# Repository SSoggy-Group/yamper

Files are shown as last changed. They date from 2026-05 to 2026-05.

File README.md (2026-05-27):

# Yamper

A tiny 3D-printed AI voice robot powered by a Raspberry Pi Zero 2 W, with OLED eyes, a speaker, microphone, button control, and a portable PiSugar battery.

## Current version

This version targets a Raspberry Pi Zero 2 WH with a PiSugar 3 1200mAh battery.

## Target hardware

- Raspberry Pi Zero 2 WH
- PiSugar 3 1200mAh Raspberry Pi Zero Battery
- 2x 0.96 inch SSD1306 I2C OLED displays
- INMP441 I2S microphone module
- MAX98357A I2S amplifier
- 3525 4 ohm 3W cavity speaker
- 16 mm momentary illuminated metal pushbutton
- M3 x 8 self-tapping screws for the case
- 20 cm female-to-female Dupont wires
- microSD card, 32 GB or bigger

## Folder layout

```text
hardware/
  v6-zero-fixed/
    stl/       3D-print files
    source/    dimensions, source notes and preview files
    renders/   concept render
software/
  yamper/        early Python app skeleton
  systemd/     service file for autostart
docs/          wiring and build notes
```

Start by printing only:

```text
hardware/v6-zero-fixed/stl/robot_v6_zero_fixed_front_shell.stl
```

Then test-fit:

1. OLEDs
2. speaker
3. mic
4. button

Only print the full set after the front shell fits.

Recommended settings:

- Material: PETG for the main body
- Layer height: 0.20 mm
- Walls: 3 or 4
- Infill: 15 to 25 percent

## Status

This is not final product-ready yet.
Known things to verify:

- speaker thickness
- MAX98357A board size
- PiSugar button location
- OLED clone fit
- button rear depth

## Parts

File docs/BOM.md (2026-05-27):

# Bill of materials

## Main parts

| Part | Version / type | Notes |
|---|---|---|
| Computer | Raspberry Pi Zero 2 WH | WH means GPIO header is already soldered |
| Battery | PiSugar 3 1200mAh Raspberry Pi Zero Battery | Clean portable power |
| Displays | 2x 0.96 inch SSD1306 I2C OLED, white | Used as eyes |
| Microphone | INMP441 I2S MEMS mic | Round MH-ET LIVE style module |
| Amplifier | MAX98357A I2S 3W Class D amp | Drives the speaker |
| Speaker | 3525 4 ohm 3W cavity speaker | 25 x 35 mm body |
| Button | 16 mm momentary illuminated metal button | Single color LED is easiest |
| Wires | 20 cm female-to-female Dupont kit | Can be split into loose wires |
| Screws | M3 x 8 self-tapping | For the printed case, not for Pi mounting |

## Notes

- Use M3 screws for the case.
- The Pi and PiSugar usually use their own small hardware.
- If the speaker has a small connector, cut it off, strip the wires, and put red/black into the MAX98357A screw terminal.

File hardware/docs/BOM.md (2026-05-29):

# Bill of Materials

| Part | Purpose | Important dimensions |
|---|---|---|
| Raspberry Pi Zero 2 WH | Main computer | 65 x 30 mm board, 58 x 23 mm mounting hole spacing |
| PiSugar 3 | Battery and power board | Pi Zero footprint area |
| 2x 0.96 inch SSD1306 OLED | Robot eyes | visible window about 23.5 x 12.9 mm, PCB about 27.5 x 27.8 mm |
| INMP441 I2S microphone | Voice input | round module, verify real board diameter |
| MAX98357A I2S amplifier | Drives the speaker | small breakout, clip included |
| 25 x 35 mm speaker | Audio output | 25 x 35 mm |
| 16 mm momentary metal button | Main button | case hole about 16.4 mm |
| M3 self-tapping screws | Close the case | M3 x 8 mm or M3 x 10 mm suggested |
| M2.5 screws | Pi/PiSugar mounting | for Pi Zero mounting holes |

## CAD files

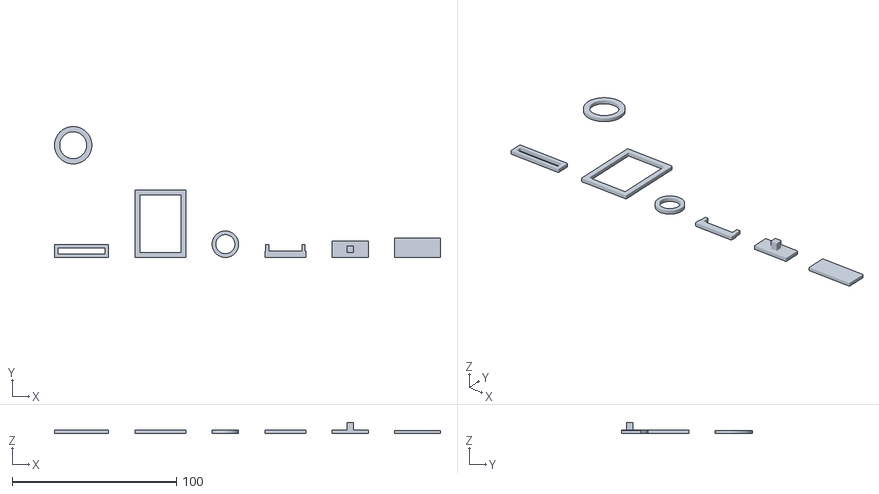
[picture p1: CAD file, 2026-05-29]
hardware/cad/print-plates/v11_small_parts_arranged_no_overlap.stl
235.2 x 79.8 x 6.90

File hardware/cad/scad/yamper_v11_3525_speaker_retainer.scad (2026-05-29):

/*
Yamper V11 mesh source for yamper_v11_3525_speaker_retainer.stl
Units: millimeters

This source keeps the restored V11 STL geometry as a plain OpenSCAD polyhedron.
It is not a new redesign. It exists so the CAD source, STL, and STEP exports stay together.
*/

module yamper_v11_3525_speaker_retainer() {
    pts = [
        [-15.5, 17.5, 2.2],
        [-15.5, 20.5, 2.2],
        [-15.5, 17.5, 0],
        [15.5, 17.5, 0],
        [-15.5, 20.5, 0],
        [15.5, 20.5, 2.2],
        [15.5, 17.5, 2.2],
        [15.5, 20.5, 0],
        [-15.5, -20.5, 2.2],
        [-15.5, -17.5, 2.2],
        [-15.5, -20.5, 0],
        [15.5, -20.5, 0],
        [-15.5, -17.5, 0],
        [15.5, -17.5, 2.2],
        [15.5, -20.5, 2.2],
        [15.5, -17.5, 0],
        [-12.5, -20.5, 0],
        [-12.5, 20.5, 2.2],
        [-12.5, -20.5, 2.2],
        [-12.5, 20.5, 0],
        [12.5, -20.5, 2.2],
        [12.5, 20.5, 2.2],
        [12.5, -20.5, 0],
        [12.5, 20.5, 0],
    ];

    tris = [
        [0, 1, 2],
        [3, 0, 2],
        [2, 1, 4],
        [4, 3, 2],
        [0, 5, 1],
        [6, 0, 3],
        [6, 5, 0],
        [1, 5, 4],
        [7, 3, 4],
        [4, 5, 7],
        [7, 6, 3],
        [5, 6, 7],
        [8, 9, 10],
        [11, 8, 10],
        [10, 9, 12],
        [12, 11, 10],
        [8, 13, 9],
        [14, 8, 11],
        [14, 13, 8],
        [9, 13, 12],
        [15, 11, 12],
        [12, 13, 15],
        [15, 14, 11],
        [13, 14, 15],
        [8, 1, 10],
        [16, 8, 10],
        [10, 1, 4],
        [4, 16, 10],
        [8, 17, 1],
        [18, 8, 16],
        [18, 17, 8],
        [1, 17, 4],
        [19, 16, 4],
        [4, 17, 19],
        [19, 18, 16],
        [17, 18, 19],
        [20, 21, 22],
        [11, 20, 22],
        [22, 21, 23],
        [23, 11, 22],
        [20, 5, 21],
        [14, 20, 11],
        [14, 5, 20],
        [21, 5, 23],
        [7, 11, 23],
        [23, 5, 7],
        [7, 14, 11],
        [5, 14, 7],
    ];

    polyhedron(points = pts, faces = tris, convexity = 10);
}

yamper_v11_3525_speaker_retainer();

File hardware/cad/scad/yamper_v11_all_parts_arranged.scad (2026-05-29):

/* Yamper V11 arranged OpenSCAD preview. Units are millimeters. */

use <yamper_v11_front_shell_fused.scad>;
use <yamper_v11_back_cover_with_pisugar_power_slot.scad>;
use <yamper_v11_oled_retainer_print_2x.scad>;
use <yamper_v11_3525_speaker_retainer.scad>;
use <yamper_v11_round_inmp441_mic_retainer.scad>;
use <yamper_v11_max98357a_clip.scad>;
use <yamper_v11_pisugar_power_button_plunger_test.scad>;
use <yamper_v11_pisugar_slot_blank_cap_optional.scad>;
use <yamper_v11_button_washer_optional.scad>;

translate([52.075001, 41.625, 0.075]) yamper_v11_front_shell_fused();
translate([171.625, 40.674999, 0.075]) yamper_v11_back_cover_with_pisugar_power_slot();
translate([16.5, 124, 0]) yamper_v11_oled_retainer_print_2x();
translate([64.5, 140.5, 0]) yamper_v11_3525_speaker_retainer();
translate([104.1, 128.1, 1.1]) yamper_v11_round_inmp441_mic_retainer();
translate([140.700001, 122, 0]) yamper_v11_max98357a_clip();
translate([180.200001, 125, 0]) yamper_v11_pisugar_power_button_plunger_test();
translate([221.200001, 126, 0]) yamper_v11_pisugar_slot_blank_cap_optional();
translate([11.4, 188.4, 1]) yamper_v11_button_washer_optional();

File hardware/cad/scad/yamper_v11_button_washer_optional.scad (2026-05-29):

/*
Yamper V11 mesh source for yamper_v11_button_washer_optional.stl
Units: millimeters

This source keeps the restored V11 STL geometry as a plain OpenSCAD polyhedron.
It is not a new redesign. It exists so the CAD source, STL, and STEP exports stay together.
*/

module yamper_v11_button_washer_optional() {
    pts = [
        [8.2, 0, -1],
        [8.174722, 0.643365, -1],
        [11.4, 0, -1],
        [11.364858, 0.894434, -1],
        [11.4, 0, 1],
        [11.364858, 0.894434, 1],
        [8.2, 0, 1],
        [8.174722, 0.643365, 1],
        [8.099045, 1.282763, -1],
        [11.259647, 1.783353, -1],
        [11.259647, 1.783353, 1],
        [8.099045, 1.282763, 1],
        [7.973433, 1.914252, -1],
        [11.085017, 2.661277, -1],
        [11.085017, 2.661277, 1],
        [7.973433, 1.914252, 1],
        [7.798664, 2.533939, -1],
        [10.842044, 3.522794, -1],
        [10.842044, 3.522794, 1],
        [7.798664, 2.533939, 1],
        [7.575812, 3.138004, -1],
        [10.532227, 4.362591, -1],
        [10.532227, 4.362591, 1],
        [7.575812, 3.138004, 1],
        [7.306253, 3.722722, -1],
        [10.157475, 5.175492, -1],
        [10.157475, 5.175492, 1],
        [7.306253, 3.722722, 1],
        [6.991649, 4.284488, -1],
        [9.720098, 5.956484, -1],
        [9.720098, 5.956484, 1],
        [6.991649, 4.284488, 1],
        [6.633939, 4.819839, -1],
        [9.222794, 6.700752, -1],
        [9.222794, 6.700752, 1],
        [6.633939, 4.819839, 1],
        [6.235329, 5.325474, -1],
        [8.668628, 7.403708, -1],
        [8.668628, 7.403708, 1],
        [6.235329, 5.325474, 1],
        [5.798275, 5.798275, -1],
        [8.061017, 8.061017, -1],
        [8.061017, 8.061017, 1],
        [5.798275, 5.798275, 1],
        [5.325474, 6.235329, -1],
        [7.403708, 8.668628, -1],
        [7.403708, 8.668628, 1],
        [5.325474, 6.235329, 1],
        [4.819839, 6.633939, -1],
        [6.700752, 9.222794, -1],
        [6.700752, 9.222794, 1],
        [4.819839, 6.633939, 1],
        [4.284488, 6.991649, -1],
        [5.956484, 9.720098, -1],
        [5.956484, 9.720098, 1],
        [4.284488, 6.991649, 1],
        [3.722722, 7.306253, -1],
        [5.175492, 10.157475, -1],
        [5.175492, 10.157475, 1],
        [3.722722, 7.306253, 1],
        [3.138004, 7.575812, -1],
        [4.362591, 10.532227, -1],
        [4.362591, 10.532227, 1],
        [3.138004, 7.575812, 1],
        [2.533939, 7.798664, -1],
        [3.522794, 10.842044, -1],
        [3.522794, 10.842044, 1],
        [2.533939, 7.798664, 1],
        [1.914252, 7.973433, -1],
        [2.661277, 11.085017, -1],
        [2.661277, 11.085017, 1],
        [1.914252, 7.973433, 1],
        [1.282763, 8.099045, -1],
        [1.783353, 11.259647, -1],
        [1.783353, 11.259647, 1],
        [1.282763, 8.099045, 1],
        [0.643365, 8.174722, -1],
        [0.894434, 11.364858, -1],
        [0.894434, 11.364858, 1],
        [0.643365, 8.174722, 1],
        [0, 8.2, -1],
        [0, 11.4, -1],
        [0, 11.4, 1],
        [0, 8.2, 1],
        [-0.643365, 8.174722, -1],
        [-0.894434, 11.364858, -1],
        [-0.894434, 11.364858, 1],
        [-0.643365, 8.174722, 1],
        [-1.282763, 8.099045, -1],
        [-1.783353, 11.259647, -1],
        [-1.783353, 11.259647, 1],
        [-1.282763, 8.099045, 1],
        [-1.914252, 7.973433, -1],
        [-2.661277, 11.085017, -1],
        [-2.661277, 11.085017, 1],
        [-1.914252, 7.973433, 1],
        [-2.533939, 7.798664, -1],
        [-3.522794, 10.842044, -1],
        [-3.522794, 10.842044, 1],
        [-2.533939, 7.798664, 1],
        [-3.138004, 7.575812, -1],
        [-4.362591, 10.532227, -1],
        [-4.362591, 10.532227, 1],
        [-3.138004, 7.575812, 1],
        [-3.722722, 7.306253, -1],
        [-5.175492, 10.157475, -1],
        [-5.175492, 10.157475, 1],
        [-3.722722, 7.306253, 1],
        [-4.284488, 6.991649, -1],
        [-5.956484, 9.720098, -1],
        [-5.956484, 9.720098, 1],
        [-4.284488, 6.991649, 1],
        [-4.819839, 6.633939, -1],
        [-6.700752, 9.222794, -1],
        [-6.700752, 9.222794, 1],
        [-4.819839, 6.633939, 1],
        [-5.325474, 6.235329, -1],
        [-7.403708, 8.668628, -1],
        [-7.403708, 8.668628, 1],
        [-5.325474, 6.235329, 1],
        [-5.798275, 5.798275, -1],
        [-8.061017, 8.061017, -1],
        [-8.061017, 8.061017, 1],
        [-5.798275, 5.798275, 1],
        [-6.235329, 5.325474, -1],
        [-8.668628, 7.403708, -1],
        [-8.668628, 7.403708, 1],
        [-6.235329, 5.325474, 1],
        [-6.633939, 4.819839, -1],
        [-9.222794, 6.700752, -1],
        [-9.222794, 6.700752, 1],
        [-6.633939, 4.819839, 1],
        [-6.991649, 4.284488, -1],
        [-9.720098, 5.956484, -1],
        [-9.720098, 5.956484, 1],
        [-6.991649, 4.284488, 1],
        [-7.306253, 3.722722, -1],
        [-10.157475, 5.175492, -1],
        [-10.157475, 5.175492, 1],
        [-7.306253, 3.722722, 1],
        [-7.575812, 3.138004, -1],
        [-10.532227, 4.362591, -1],
        [-10.532227, 4.362591, 1],
        [-7.575812, 3.138004, 1],
        [-7.798664, 2.533939, -1],
        [-10.842044, 3.522794, -1],
        [-10.842044, 3.522794, 1],
        [-7.798664, 2.533939, 1],
        [-7.973433, 1.914252, -1],
        [-11.085017, 2.661277, -1],
        [-11.085017, 2.661277, 1],
        [-7.973433, 1.914252, 1],
        [-8.099045, 1.282763, -1],
        [-11.259647, 1.783353, -1],
        [-11.259647, 1.783353, 1],
        [-8.099045, 1.282763, 1],
        [-8.174722, 0.643365, -1],
        [-11.364858, 0.894434, -1],
        [-11.364858, 0.894434, 1],
        [-8.174722, 0.643365, 1],
        [-8.2, 0, -1],
        [-11.4, 0, -1],
        [-11.4, 0, 1],
        [-8.2, 0, 1],
        [-8.174722, -0.643365, -1],
        [-11.364858, -0.894434, -1],
        [-11.364858, -0.894434, 1],
        [-8.174722, -0.643365, 1],
        [-8.099045, -1.282763, -1],
        [-11.259647, -1.783353, -1],
        [-11.259647, -1.783353, 1],
        [-8.099045, -1.282763, 1],
        [-7.973433, -1.914252, -1],
        [-11.085017, -2.661277, -1],
        [-11.085017, -2.661277, 1],
        [-7.973433, -1.914252, 1],
        [-7.798664, -2.533939, -1],
        [-10.842044, -3.522794, -1],
        [-10.842044, -3.522794, 1],
        [-7.798664, -2.533939, 1],
        [-7.575812, -3.138004, -1],
        [-10.532227, -4.362591, -1],
        [-10.532227, -4.362591, 1],
        [-7.575812, -3.138004, 1],
        [-7.306253, -3.722722, -1],
        [-10.157475, -5.175492, -1],
        [-10.157475, -5.175492, 1],
        [-7.306253, -3.722722, 1],
        [-6.991649, -4.284488, -1],
        [-9.720098, -5.956484, -1],
        [-9.720098, -5.956484, 1],
        [-6.991649, -4.284488, 1],
        [-6.633939, -4.819839, -1],
        [-9.222794, -6.700752, -1],
        [-9.222794, -6.700752, 1],
        [-6.633939, -4.819839, 1],
        [-6.235329, -5.325474, -1],
        [-8.668628, -7.403708, -1],
        [-8.668628, -7.403708, 1],
        [-6.235329, -5.325474, 1],
        [-5.798275, -5.798275, -1],
        [-8.061017, -8.061017, -1],
        [-8.061017, -8.061017, 1],
        [-5.798275, -5.798275, 1],
        [-5.325474, -6.235329, -1],
        [-7.403708, -8.668628, -1],
        [-7.403708, -8.668628, 1],
        [-5.325474, -6.235329, 1],
        [-4.819839, -6.633939, -1],
        [-6.700752, -9.222794, -1],
        [-6.700752, -9.222794, 1],
        [-4.819839, -6.633939, 1],
        [-4.284488, -6.991649, -1],
        [-5.956484, -9.720098, -1],
        [-5.956484, -9.720098, 1],
        [-4.284488, -6.991649, 1],
        [-3.722722, -7.306253, -1],
        [-5.175492, -10.157475, -1],
        [-5.175492, -10.157475, 1],
        [-3.722722, -7.306253, 1],
        [-3.138004, -7.575812, -1],
        [-4.362591, -10.532227, -1],
        [-4.362591, -10.532227, 1],
        [-3.138004, -7.575812, 1],
        [-2.533939, -7.798664, -1],
        [-3.522794, -10.842044, -1],
        [-3.522794, -10.842044, 1],
        [-2.533939, -7.798664, 1],
        [-1.914252, -7.973433, -1],
        [-2.661277, -11.085017, -1],
        [-2.661277, -11.085017, 1],
        [-1.914252, -7.973433, 1],
        [-1.282763, -8.099045, -1],
        [-1.783353, -11.259647, -1],
        [-1.783353, -11.259647, 1],
        [-1.282763, -8.099045, 1],
        [-0.643365, -8.174722, -1],
        [-0.894434, -11.364858, -1],
        [-0.894434, -11.364858, 1],
        [-0.643365, -8.174722, 1],
        [0, -8.2, -1],
        [0, -11.4, -1],
        [0, -11.4, 1],
        [0, -8.2, 1],
        [0.643365, -8.174722, -1],
        [0.894434, -11.364858, -1],
        [0.894434, -11.364858, 1],
        [0.643365, -8.174722, 1],
        [1.282763, -8.099045, -1],
        [1.783353, -11.259647, -1],
        [1.783353, -11.259647, 1],
        [1.282763, -8.099045, 1],
        [1.914252, -7.973433, -1],
        [2.661277, -11.085017, -1],
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

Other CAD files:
hardware/cad/step/yamper_v11_oled_retainer_print_2x.step
hardware/cad/step/yamper_v11_pisugar_slot_blank_cap_optional.step
hardware/cad/step/yamper_v11_max98357a_clip.step
hardware/cad/step/yamper_v11_3525_speaker_retainer.step
hardware/cad/step/yamper_v11_round_inmp441_mic_retainer.step
hardware/cad/step/yamper_v11_pisugar_power_button_plunger_test.step
hardware/cad/step/yamper_v11_button_washer_optional.step
hardware/cad/scad/yamper_v11_max98357a_clip.scad
hardware/cad/scad/import_wrappers/yamper_v11_3525_speaker_retainer_import.scad
hardware/cad/scad/import_wrappers/yamper_v11_back_cover_with_pisugar_power_slot_import.scad
hardware/cad/scad/import_wrappers/yamper_v11_button_washer_optional_import.scad
hardware/cad/scad/import_wrappers/yamper_v11_front_shell_fused_import.scad
hardware/cad/scad/import_wrappers/yamper_v11_max98357a_clip_import.scad
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

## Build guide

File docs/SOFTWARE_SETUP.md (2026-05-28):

# Yamper Software Setup Guide

Complete step-by-step instructions for setting up Yamper on a fresh Raspberry Pi Zero 2 WH.

No desktop environment, no HDMI, no keyboard required after initial setup.

---

## 1. Flash the SD card

1. Download and install **Raspberry Pi Imager** on your computer.
2. Insert your microSD card (32 GB or larger).
3. Open Raspberry Pi Imager and choose:
   - **Device:** Raspberry Pi Zero 2 W
   - **OS:** Raspberry Pi OS Lite (64-bit)
   - **Storage:** your SD card
4. Click the **gear icon** (⚙️) or "Edit Settings" before writing:
   - ✅ Set hostname: `yamper`
   - ✅ Enable SSH → Use password authentication
   - ✅ Set username: `pi` and a password you'll remember
   - ✅ Configure wireless LAN → enter your WiFi name and password
   - ✅ Set locale and timezone
5. Click **Write** and wait for it to finish.

## 2. First boot

1. Insert the SD card into the Pi and power it on.
2. Wait about 60–90 seconds for the first boot.
3. From your computer, connect via SSH:

```bash
ssh pi@yamper.local
```

> If `yamper.local` doesn't work, find the Pi's IP address in your router's admin page and use `ssh pi@<IP>`.

4. Update the system:

```bash
sudo apt update && sudo apt upgrade -y
```

## 3. Enable I2C (for the OLED eyes)

```bash
sudo raspi-config
```

Navigate to: **Interface Options → I2C → Enable → Finish**

Verify I2C is working:

```bash
sudo apt install -y i2c-tools
i2cdetect -y 1
```

You should see `3c` (and possibly `3d`) in the grid. These are your OLED displays.

> **Important (OLED Address Conflict):** Yamper uses two OLED screens on the same I2C bus. To prevent conflicts, they MUST have different addresses (`0x3C` and `0x3D`). Most screens default to `0x3C`. You will likely need to move the resistor on the back of one screen from `0x78` to `0x7A` (which maps to `0x3D`).

## 4. Enable I2S audio (for mic and speaker)

Edit the boot configuration:

```bash
sudo nano /boot/firmware/config.txt
```

> **Note:** On older Raspberry Pi OS versions, the file might be at `/boot/config.txt` instead.

Add these lines at the bottom:

```ini
# I2S audio for INMP441 mic and MAX98357A amp
dtoverlay=googlevoicehat-soundcard
```

> **Alternative:** If `googlevoicehat-soundcard` doesn't work, try:
> ```ini
> dtoverlay=hifiberry-dac
> dtoverlay=i2s-mmap
> ```

Save and reboot:

```bash
sudo reboot
```

After reboot, SSH in again and check:

```bash
arecord -l
aplay -l
```

You should see at least one recording device and one playback device.

> **Optional:** If you have multiple audio devices, you can set `MIC_DEVICE_INDEX` and `SPEAKER_DEVICE_INDEX` in your `.env` file to force a specific device. You can run `python3 -c "import sounddevice as sd; print(sd.query_devices())"` inside the venv to find your device numbers.

## 5. Install system dependencies

```bash
sudo apt install -y \
  python3-pip \
  python3-venv \
  python3-dev \
  libopenblas-dev \
  libasound2-dev \
  portaudio19-dev \
  ffmpeg \
  git
```

## 6. Clone the project

```bash
cd ~
git clone https://github.com/SSoggy-Group/yamper.git
cd yamper/software
```

> Replace `SSoggy-Group` with your actual GitHub username if you forked the repository.

## 7. Create a Python virtual environment

```bash
python3 -m venv .venv
source .venv/bin/activate
```

From now on, always activate the venv before running Yamper commands:

```bash
source ~/yamper/software/.venv/bin/activate
```

## 8. Install Python packages

```bash
pip install -r requirements.txt
```

This installs: `openai`, `Pillow`, `luma.oled`, `RPi.GPIO`, `sounddevice`, `numpy`, `python-dotenv`, `pydub`.

> **Note:** On the Pi Zero 2 W this may take 5–10 minutes. Be patient.

## 9. Set up your OpenAI API key

```bash
cp ../.env.example .env
nano .env
```

Replace `sk-your-key-here` with your real OpenAI API key. Save and exit (`Ctrl+X`, then `Y`, then `Enter`).

> Get an API key at https://platform.openai.com/api-keys

## 10. Test the hardware

Run each test one at a time to verify your wiring:

### Test the OLED eyes

```bash
python3 -m yamper.test_eyes
```

You should see different eye animations cycle on the OLED screens.

### Test the button

```bash
python3 -m yamper.test_button
```

Press the button — you should see messages in the terminal. The LED should light up while the button is held. Press `Ctrl+C` to stop.

### Test the microphone

```bash
python3 -m yamper.test_mic
```

Speak during the 3-second recording. It will play back what it heard.

### Test the speaker

```bash
python3 -m yamper.test_speaker
```

You should hear a 440 Hz beep tone.

### Test the OpenAI API

```bash
python3 -m yamper.test_openai
```

You should hear the robot say a greeting.

## 11. Run Yamper manually

Once all tests pass:

```bash
python3 -m yamper.main
```

If Yamper cannot connect to the internet, its eyes will show a WiFi setup screen and it will create a hotspot named **Yamper Setup**. Connect to this network on your phone or computer and open `http://192.168.4.1:8080` in your browser to enter your home WiFi credentials.

Once connected to the internet, press the button, speak, and Yamper will respond!

Press `Ctrl+C` to stop.

## 12. Enable autostart on boot

Copy the systemd service file:

```bash
sudo cp ~/yamper/software/systemd/yamper.service /etc/systemd/system/
sudo systemctl daemon-reload
sudo systemctl enable yamper
sudo systemctl start yamper
```

Check that it's running:

```bash
sudo systemctl status yamper
```

View live logs:

```bash
journalctl -u yamper -f
```

Now Yamper will start automatically every time the Pi boots.

### To stop or restart:

```bash
sudo systemctl stop yamper
sudo systemctl restart yamper
```

### To disable autostart:

```bash
sudo systemctl disable yamper
```

---

## Troubleshooting

### "No OLED found"

- Run `i2cdetect -y 1` and check that `3c` or `3d` appears.
- Verify SDA → GPIO 2, SCL → GPIO 3.
- Check VCC is connected to 3.3V.

### "No sound device" or "recording failed"

- Check `arecord -l` and `aplay -l`.
- Make sure the I2S overlay is in `/boot/firmware/config.txt`.
- Reboot after changing config.txt.
- Wiring: BCLK → GPIO 18, LRCLK → GPIO 19, DIN → GPIO 20, DOUT → GPIO 21.

### "OPENAI_API_KEY not set"

- Make sure `software/.env` exists and has a valid key.
- The key must start with `sk-`.

### "WiFi error eyes" (no-wifi symbol on screen)

- Check WiFi: `ping 8.8.8.8`
- Reconnect: `sudo raspi-config` → System Options → Wireless LAN.

### Button not working

- Check wiring: one switch leg to GPIO 17, other to GND.
- The code uses an internal pull-up resistor, so no external resistor is needed.

### MP3 playback fails

- Make sure `ffmpeg` is installed: `sudo apt install ffmpeg`
- The `pydub` package uses `ffmpeg` to decode MP3 files from OpenAI TTS.

### Audio too quiet or too loud

- Use `alsamixer` to adjust volume: `alsamixer`
- Use arrow keys to change levels. Press `Esc` to save.

---

## File layout

```
yamper/
├── .env.example                # copy to software/.env
├── docs/
│   └── SOFTWARE_SETUP.md       # this file
├── software/
│   ├── .env                    # your API key (not in git)
│   ├── requirements.txt        # Python dependencies
│   ├── systemd/
│   │   └── yamper.service      # autostart service
│   └── yamper/
│       ├── __init__.py
│       ├── config.py           # all settings and pin numbers
│       ├── main.py             # main app loop
│       ├── eyes.py             # OLED eye animations
│       ├── button.py           # GPIO button handler
│       ├── audio.py            # mic, speaker, OpenAI API
│       ├── test_eyes.py        # test: OLED displays
│       ├── test_button.py      # test: push button
│       ├── test_mic.py         # test: microphone
│       ├── test_speaker.py     # test: speaker
│       └── test_openai.py      # test: OpenAI API
└── hardware/
    └── ...                     # 3D print files
```

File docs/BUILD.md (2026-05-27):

# Build notes

## Mechanical layout

- Back opens with 4 M3 screws.
- Raspberry Pi Zero 2 WH and PiSugar sit on the back cover.
- OLEDs mount behind the two front eye windows.
- Speaker sits behind the smaller front grille.
- Mic sits behind the small round hole pattern.
- MAX98357A sits in the side pocket.
- Retainers stop the parts from falling inward.

## First print checklist

Print only the front shell first.

Test these parts:

- OLED board fits in the eye pockets
- speaker fits in the 25 x 35 mm pocket
- mic fits the 14 mm holder
- 16 mm button fits the top hole
- screw posts do not look weak

## Do not trust the full print yet

This version is a beta fit model. If a part is off by 1 to 2 mm, update the CAD before printing the final clean version.

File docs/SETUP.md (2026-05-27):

# Raspberry Pi setup notes

Recommended OS:

- Raspberry Pi OS Lite
- no desktop

Goal:

- boot headless
- connect to WiFi
- run Mimo automatically
- show simple boot/status on OLED
- shut down after idle time to save battery

Estimated boot time:

- normal: 25 to 45 seconds
- optimized: 15 to 30 seconds

Power-saving ideas:

- turn OLEDs off when idle
- disable HDMI
- disable Bluetooth if unused
- keep speaker amp disabled until speaking
- auto shutdown after 10 to 15 minutes idle

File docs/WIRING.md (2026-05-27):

# Wiring plan

This is the first wiring plan for Mimo V6 Zero.

## OLED eyes

Both OLED displays use I2C.

| OLED pin | Raspberry Pi pin |
|---|---|
| VCC | 3.3V or 5V |
| GND | GND |
| SCL | GPIO 3 / SCL |
| SDA | GPIO 2 / SDA |

Important: many cheap OLEDs use the same I2C address. If both screens show the same thing, use an I2C multiplexer or buy OLEDs with changeable address. For the first version, mirrored eyes are acceptable.

## INMP441 microphone

| INMP441 pin | Raspberry Pi pin |
|---|---|
| VDD | 3.3V |
| GND | GND |
| SCK | I2S BCLK |
| WS | I2S LRCLK |
| SD | I2S data input |
| L/R | GND |

## MAX98357A amplifier

| MAX98357A pin | Raspberry Pi pin |
|---|---|
| VIN / VCC | 5V or 3.3V, depending on module |
| GND | GND |
| BCLK | I2S BCLK |
| LRC | I2S LRCLK |
| DIN | I2S data output |
| SD | optional GPIO for amp enable |
| Speaker + / - | speaker red / black |

## Button

The button has 2 parts:

1. the switch contacts
2. the LED ring

Use the switch as a normal GPIO input with pull-up or pull-down.

The LED ring depends on the exact voltage version. If it is the 3 to 6 V version, it can be powered from 3.3V or 5V with care. If it is the 12 to 24 V version, do not connect it directly.

## First power-on safety

Before plugging everything in:

- check 5V and 3.3V lines
- check GND is common
- do not short speaker wires
- do not power the LED ring if you are unsure about its voltage

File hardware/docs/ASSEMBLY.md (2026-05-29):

# Assembly

## Front shell

1. Place the two OLED screens behind the eye openings.
2. Use the OLED retainers to stop the OLEDs from falling inward.
3. Place the 25 x 35 mm speaker behind the speaker grille.
4. Use the speaker retainer to hold the speaker.
5. Place the INMP441 microphone behind the five mic holes.
6. Use the round mic retainer to hold the mic module.
7. Place the MAX98357A amplifier in its clip.
8. Install the 16 mm button in the top hole.

## Back cover

1. Mount the Raspberry Pi Zero 2 WH and PiSugar stack to the back cover standoffs.
2. Check that the PiSugar button lines up with the long power slot.
3. Use the plunger only after checking alignment with the real board.

## Closing the case

1. Put the back cover on the front shell.
2. Insert M3 self-tapping screws from the outside of the back cover.
3. The screws pass through the back cover and bite into the screw bosses in the front shell.
4. Do not overtighten.

Do not screw into or through the battery cell.

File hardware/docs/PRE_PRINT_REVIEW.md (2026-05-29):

# Pre-print Review

This design has not been physically verified yet.

Check before printing:
- OLED window size and spacing
- Speaker grille size
- Mic hole placement
- 16 mm button fit
- PiSugar power slot alignment
- Screw hole fit
- Back cover alignment

Still needs physical testing:
- OLED PCB/header fit
- Speaker retainer grip
- Mic retainer fit
- MAX98357A clip fit
- Pi/PiSugar stack depth
- M3 self-tapping screw bite
- PiSugar button plunger alignment

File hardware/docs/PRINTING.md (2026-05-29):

# Printing

## Front shell

- Front face flat on the bed
- Inside facing upward
- Layer height: 0.20 mm
- Wall loops: 3
- Infill: 15%
- Supports: off first

## Back cover

- Outside face flat on the bed
- Standoffs facing upward
- Layer height: 0.20 mm
- Wall loops: 3
- Infill: 15%

## Small parts

Print the retainers flat.

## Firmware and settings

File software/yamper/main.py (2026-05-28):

import signal
import subprocess
import sys
import time

from . import audio
from . import config
from . import wifi
from . import wifi_setup
from .button import Button
from .eyes import Eyes



def cleanup(eyes, button):
    print("cleaning up hardware...")
    eyes.set_state("sleep")
    time.sleep(0.5)
    eyes.stop()
    button.cleanup()
    print("bye!")

def process_audio_interaction(eyes, button, history):
    print("button pressed, listening...")
    button.set_led(False)
    eyes.set_state("listening")
    time.sleep(0.15)
    
    press_start = time.time()
    shutdown_requested = [False]

    def check_button():
        if not button.is_pressed():
            return False
        if time.time() - press_start >= config.SHUTDOWN_HOLD_SECONDS:
            shutdown_requested[0] = True
            return False
        return True

    wav_bytes = audio.record_while_pressed(check_button)
    
    if shutdown_requested[0]:
        return "SHUTDOWN"

    if not wav_bytes:
        print("audio capture failed :(")
        eyes.set_state("error")
        time.sleep(2.0)
        eyes.set_state("idle")
        button.set_led(True)
        return history

    print("thinking...")
    eyes.set_state("thinking")

    text = audio.transcribe(wav_bytes)
    if not text:
        print("couldn't understand that")
        eyes.set_state("error")
        time.sleep(2.0)
        eyes.set_state("idle")
        button.set_led(True)
        return history
        
    print("user said:", text)
    reply, history = audio.chat(text, history)
    
    if not reply:
        print("llm failed")
        eyes.set_state("error")
        time.sleep(2.0)
        eyes.set_state("idle")
        button.set_led(True)
        return history
        
    print("yamper says:", reply)
    mp3_data = audio.text_to_speech(reply)
    
    if not mp3_data:
        print("tts failed")
        eyes.set_state("error")
        time.sleep(2.0)
        eyes.set_state("idle")
        button.set_led(True)
        return history

    print("speaking...")
    eyes.set_state("speaking")
    audio.play_mp3_bytes(mp3_data)

    eyes.set_state("idle")
    button.set_led(True)
    print("done, back to idle")
    return history


def check_force_setup(button):
    if not button.is_pressed():
        return False
    print(f"button is held, waiting {config.WIFI_SETUP_FORCE_HOLD_SECONDS}s to check for force setup...")
    start_hold = time.time()
    while button.is_pressed():
        if time.time() - start_hold >= config.WIFI_SETUP_FORCE_HOLD_SECONDS:
            print("force setup triggered!")
            return True
        time.sleep(0.1)
    return False

def handle_wifi_setup(eyes, force_setup, is_running_func):
    if is_running_func():
        print("checking internet...")
    internet_working = wifi.internet_ok()

    while is_running_func() and (force_setup or not internet_working):
        if force_setup:
            print("force setup requested.")
        else:
            print("no internet, entering setup mode...")
            
        success = wifi_setup.run_setup_mode(eyes)
        if success:
            force_setup = False
            print("setup complete, checking internet again...")
            internet_working = wifi.internet_ok()
        else:
            print("setup mode failed or aborted, retrying in a moment...")
            time.sleep(2)


def run_robot():
    print("starting yamper...")

    eyes = Eyes()
    eyes.start()
    eyes.set_state("boot")
    time.sleep(1.5)

    if not audio.has_sd and sys.platform != "darwin":
        print("WARNING: sounddevice not found! Audio will not work.")



    button = Button()
    history = []
    
    running = True

    def on_exit(signum, frame):
        nonlocal running
        print(f"\ngot signal {signum}, stopping...")
        running = False

    import threading
    if threading.current_thread() is threading.main_thread():
        signal.signal(signal.SIGTERM, on_exit)
        signal.signal(signal.SIGINT, on_exit)

    force_setup = check_force_setup(button)
    handle_wifi_setup(eyes, force_setup, lambda: running)

    if not running:
        cleanup(eyes, button)
        sys.exit(0)

    if config.USE_FREE_AI:
        if not config.HACKCLUB_API_KEY or config.HACKCLUB_API_KEY == "sk-your-key-here":
            print("ERROR: HACKCLUB_API_KEY is not set in config/environment.")
            eyes.set_state("error")
            time.sleep(5)
            eyes.stop()
            sys.exit(1)
    else:
        if not config.OPENAI_API_KEY or config.OPENAI_API_KEY == "sk-your-key-here":
            print("ERROR: OPENAI_API_KEY is not set in config/environment.")
            eyes.set_state("error")
            time.sleep(5)
            eyes.stop()
            sys.exit(1)

    print("wifi ok! yamper is ready.")
    eyes.set_state("idle")
    button.set_led(True)

    while running:
        if not button.wait_for_press(timeout=1.0):
            continue

        res = process_audio_interaction(eyes, button, history)
        if res == "SHUTDOWN":
            print("long press detected! initiating shutdown...")
            eyes.set_state("sleep")
            time.sleep(1.0)
            subprocess.run(["sudo", "shutdown", "-h", "now"])
            running = False
            break
        else:
            history = res

    cleanup(eyes, button)

def main():
    if sys.platform == "darwin":
        import threading
        print("initializing mac screens...")
        from . import eyes
        eyes.make_device(config.OLED_LEFT_ADDR)
        
        t = threading.Thread(target=run_robot, daemon=True)
        t.start()
        
        try:
            while t.is_alive():
                if hasattr(eyes, '_tk_root') and eyes._tk_root is not None:
                    try: eyes._tk_root.pump_gui()
                    except Exception: break
                time.sleep(0.05)
        except KeyboardInterrupt:
            print("\nstopping...")
    else:
        run_robot()

if __name__ == "__main__":
    main()

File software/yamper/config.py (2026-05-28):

import os
from dotenv import load_dotenv

# load api keys and stuff
load_dotenv()

OPENAI_API_KEY = os.getenv("OPENAI_API_KEY", "")
HACKCLUB_API_KEY = os.getenv("HACKCLUB_API_KEY", "")
USE_FREE_AI = os.getenv("USE_FREE_AI", "False").lower() == "true"

WHISPER_MODEL = "whisper-1"
CHAT_MODEL = "qwen/qwen3-32b" if USE_FREE_AI else "gpt-4o-mini"
TTS_MODEL = "tts-1"
TTS_VOICE = "nova"

SYSTEM_PROMPT = "You are Yamper, a tiny friendly robot. Keep answers short — one or two sentences is best. Be cheerful and helpful."
MAX_HISTORY = 10

# pins
BUTTON_PIN = 17       
BUTTON_LED_PIN = 27   

# displays
OLED_WIDTH = 128
OLED_HEIGHT = 64
OLED_LEFT_ADDR = 0x3C
OLED_RIGHT_ADDR = 0x3D
I2C_PORT = 1

# audio settings
MIC_SAMPLE_RATE = 16000
MIC_CHANNELS = 1
MIC_DTYPE = "int16"

TTS_SAMPLE_RATE = 24000
SPEAKER_CHANNELS = 1

_mic_idx = os.getenv("MIC_DEVICE_INDEX", "")
MIC_DEVICE_INDEX = int(_mic_idx) if _mic_idx.isdigit() else None
_spkr_idx = os.getenv("SPEAKER_DEVICE_INDEX", "")
SPEAKER_DEVICE_INDEX = int(_spkr_idx) if _spkr_idx.isdigit() else None

MAX_RECORD_SECONDS = 15
SILENCE_THRESHOLD = 400
SILENCE_DURATION = 1.5

# system
SHUTDOWN_HOLD_SECONDS = 10.0

# network
WIFI_CHECK_HOST = "dns.google"
WIFI_CHECK_TIMEOUT = 3
WIFI_RETRY_INTERVAL = 10

WIFI_SETUP_AP_SSID = "Yamper Setup"
WIFI_SETUP_AP_PASSWORD = ""
WIFI_SETUP_IP = "192.168.4.1"  # nosec
WIFI_SETUP_PORT = 8080
WIFI_SETUP_FORCE_HOLD_SECONDS = 5.0
WIFI_CONNECT_TIMEOUT = 30
WIFI_MOCK_MODE = False

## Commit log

2026-05-27 Initialize Yamper codebase with docs, hardware (stl/source), and software packages including setup files and gitignore
    [robot_v6_zero_fixed_3525_speaker_retainer.stl, robot_v6_zero_fixed_assembly_preview_not_for_printing.obj, robot_v6_zero_fixed_back_cover.stl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]
2026-05-28 feat: add macOS fake gpio for button testing
2026-05-28 feat: wire up setup flow and refactor main loop
2026-05-28 Fix Yamper startup flow, WiFi setup, and reliability issues
    [config.py, eyes.py, main.py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]
2026-05-28 Update physical robot 3D models to newest version
    [robot_v6_zero_fixed_3525_speaker_retainer.stl, robot_v6_zero_fixed_assembly_preview_not_for_printing.obj, robot_v6_zero_fixed_back_cover.stl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]
2026-05-28 fix: update wifi setup portal, connect flow, and failure recovery
    [config.py, eyes.py, wifi.py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]
2026-05-28 use specific audio devices in code
2026-05-29 update robot CAD
    [yamper_v11_3525_speaker_retainer.stl, yamper_v11_button_washer_optional.stl, yamper_v11_max98357a_clip.stl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]
2026-05-29 refactor: modularize hardware CAD project by replacing single source with individual SCAD, STEP, and import wrapper files.
    [v11_small_parts_arranged_no_overlap.stl, yamper_v11_3525_speaker_retainer.scad, yamper_v11_3525_speaker_retainer.step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]
